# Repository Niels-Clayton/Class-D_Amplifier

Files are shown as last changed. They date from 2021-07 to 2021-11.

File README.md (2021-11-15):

# [D-Class Amplifier](https://niels-clayton.github.io/D-Class_Amplifier/)
ECEN405 Class-D amplifier group project

**Team members:**

- Daniel Eisen
- Nickolai Wolfe
- Niels Clayton

---
## Input Filter Stage

- The input stage will use two active filters, a 10Hz corner frequency high pass filter, and a 200Hz corner frequency low pass filter. This will provide an overall filter passband of 10Hz - 200Hz.

---
## S-PWM Generation

- It is important to be able to effectively filter out the switching frequency of the sinusoidal pulse width modulated (SPWM) signal output. because of this, we want to ensure that the switching frequency is at least two decades above the maximum output frequency. This will ensure an attenuation of at least 40dB of the switching noise by the output filter.

- Our output frequency range is 10Hz - 200Hz. To achieve the required attenuation of the switching frequency, it will nee to be 20kHz.

---
## Power Stage
- 2x IR21834PBF drivers
  - V_offset: 600V max
  - I_o+-: 1.4A/1.8A
  - T_on/off: 180ns/220ns
  - MT: 35ns
  - V_cc: 10-20V (single)
  - V_in: Vss+5V
- 4x PHP23NQ11T,127 Fets
  - minimum BV_dss of 45V
  - Actual: 110V
  - Gate Charge Qg: 10nC
  - Rdson: 49m 

https://www.infineon.com/dgdl/Infineon-Using_Monolithic_Voltage_Gate_Drivers-AN-v01_00-EN.pdf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
---
## Output filter
Signal freq max of 200Hz, Switching frequency of ~25kHz
Place corner frequency of filter at 2kHz (decade centred)
mes

https://datasheets.maximintegrated.com/en/ds/MAX4295.pdf

Figure 4c. Alternate Balanced 2-Pole Filter

Balanced 2-Pole (Figure 4b):
A  balanced  2-pole  filter  does  not  have  the  common-
mode swing problem of the single-ended filter.
C = 2 / (√2 ✕ RL ✕ ωo), L = (√2 ✕ RL)/(2 ✕ ωo); choosing
fo =  30kHz  and  RL =  4Ω,  C1a  =  C1b  =  2.0μF,  L1a  =
L1b = 15μH.
A single capacitor connected across RL, with a value of
CL = 1/(√2 ✕ RL ✕ ωo), can be used in place of C1a and
C1b.  However,  the  configuration  as  shown  gives  an
improved  rejection  to  common-mode  signal  compo-
nents  of  OUT+_  and  OUT-_.    If  the  single  capacitor
scheme is used, additional capacitors (Ca and Cb) can
be  added  from  each  side  of  RL,  providing  a  high-fre-
quency  short  to  ground  (Figure  4c).  These  capacitors
should be approximately 0.2 ✕ CL.

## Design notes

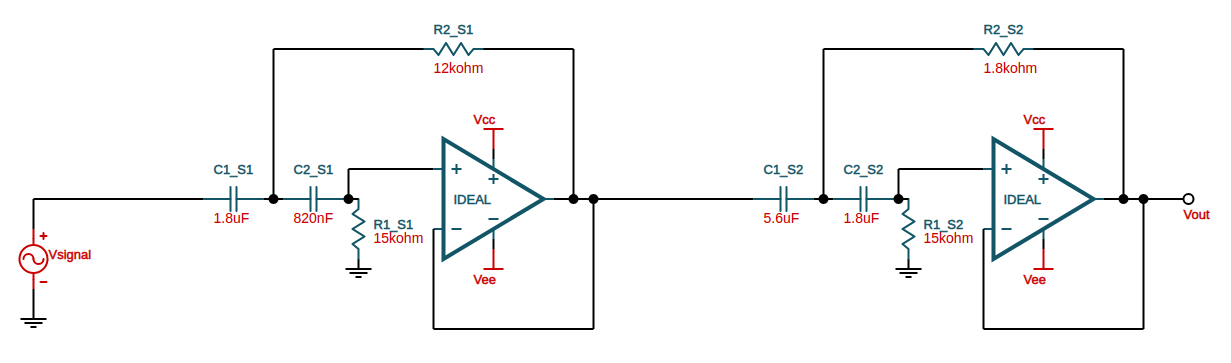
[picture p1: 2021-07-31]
docs/images/input_HPF_design.png

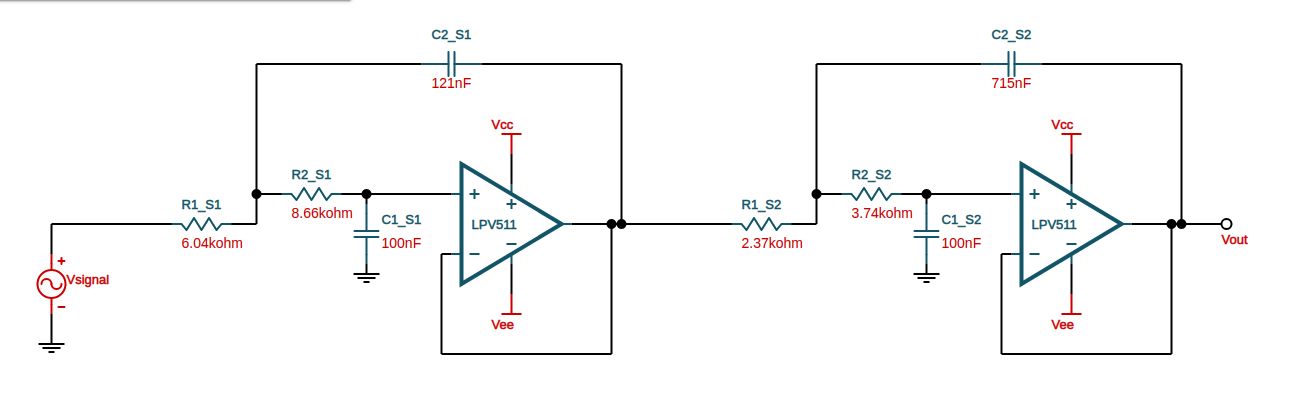
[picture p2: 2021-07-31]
docs/images/input_LPF_design.png

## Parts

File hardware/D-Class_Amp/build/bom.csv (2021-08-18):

Supplier | Part Number | Qty | Description
Digi-Key | CL21A106KOQNNWE | 12 | 10uF 16V
Digi-Key | UVR1H102MHD1TO | 3 | 1000uF 50V
Digi-Key | 885012207051 | 6 | 1uF 16V
Digi-Key | 865080142007 | 3 | 100uF 6.3V
Digi-Key | CL21B154KOANNNC | 3 | 150nF 16V
Digi-Key | 885012207045 | 15 | 100nF 16V
Digi-Key | L21A225KOFNNNE | 3 | 2.2uF 16V
Digi-Key | CL21B684KOFNNNG | 3 | 680nF 16V
Digi-Key | C0805C125K4PAC7800 | 3 | 1.2uF 16V
Digi-Key | 885012207040 | 3 | 15nF 16V
Digi-Key | 865080640001 | 6 | 1uF 50V
Digi-Key | C4AQJLU5100M19J | 3 | 10u 700V
Digi-Key | CL21B474KBFNNNG | 6 | 0.47uF 50V
Digi-Key | UG1B-E3/54 | 6 | Vishay Diode 100V 1A
Digi-Key | HCTI-150-5.0 | 6 | 150uF
Digi-Key | PHP23NQ11T,127 | 12 | PHP23NQ11T
Digi-Key | RC0805JR-0710KL | 27 | 10k
Digi-Key | RC0805JR-074K3L | 3 | 4.3k
Digi-Key | RC0805JR-075K6L | 3 | 5.6k
Digi-Key | CRCW08051K50FKEAC | 3 | 1.5k
Digi-Key | ERA-6AED242V | 3 | 2.4k
Digi-Key | RC0805JR-078K2L | 3 | 8.2k
Digi-Key | RC0805JR-0715KL | 3 | 15k
Digi-Key | RC0805JR-0710KL | 3 | 1k
Digi-Key | ERJ-6ENF10R0V | 12 | 10 ohms
Digi-Key | CT6EP203 | 3 | 20k
Digi-Key | CT6EP502 | 3 | 5k
Digi-Key | CT6EP102 | 3 | 1k
Digi-Key | NCP1117DT12G | 3 | IC REG LINEAR 12V 1A DPAK
Digi-Key | MCP1799T-5002H/TT | 3 | IC REG LINEAR 5V 80MA SOT23-3
Digi-Key | LM324DR | 3 | IC OPAMP GP 4 CIRCUIT 14SOIC
Digi-Key | TL972IDR | 3 | IC OPAMP GP 2 CIRCUIT 8SOIC
Digi-Key | LMV393S-13 | 3 | IC COMPARATOR TINY LV 8-SO
Digi-Key | IR21834SPBFDKR-ND | 6 | IC GATE DRVR HALF-BRIDGE 14SOIC

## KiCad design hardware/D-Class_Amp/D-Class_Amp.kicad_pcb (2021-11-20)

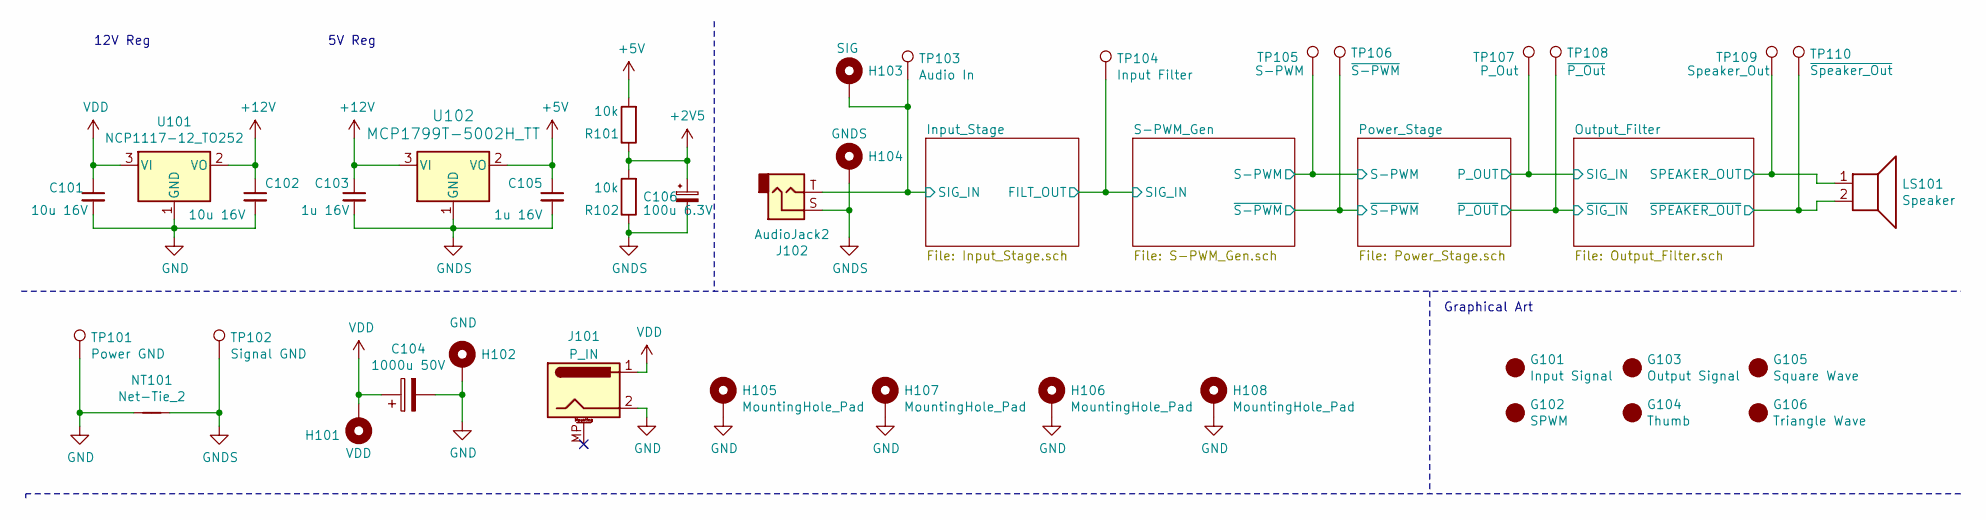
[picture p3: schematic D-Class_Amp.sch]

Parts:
C101, C102: 10u 16V; C_0805_2012Metric_Pad1.18x1.45mm_HandSolder; Part Number CL21A106KOQNNWE; DigiKey Price 0.34
C103, C105: 1u 16V; C_0805_2012Metric_Pad1.18x1.45mm_HandSolder; Part Number 885012207051; DigiKey Price 0.16
C104: 1000u 50V; CP_Radial_D10.0mm_P5.00mm; Part Number UVR1H102MHD1TO; DigiKey Price 1
C106: 100u 6.3V; CP_Elec_4x5.4; Part Number 885012207051; DigiKey Price 0.16
G101: Input Signal; sine
G102: SPWM
G103: Output Signal; sine
G104: Thumb; thumb
G105: Square Wave; square
G106: Triangle Wave; triangle
H101: VDD; MountingHole_3mm_Pad_Via
H102: GND; MountingHole_3mm_Pad_Via
H103: SIG; MountingHole_3mm_Pad_Via
H104: GNDS; MountingHole_3mm_Pad_Via
H105, H106, H107, H108: MountingHole_Pad; MountingHole_3.2mm_M3_ISO14580_Pad
J101: P_IN; BarrelJack_Horizontal; Part Number PJ-002BH; DigiKey Price 1.20
J102: AudioJack2; CUI_MJ-63022A; Part Number MJ-63022A; DigiKey Price 2.27
LS101: Speaker
NT101: Net-Tie_2; NetTie-2_SMD_Pad2.0mm
R101, R102: 10k; R_0805_2012Metric_Pad1.20x1.40mm_HandSolder; Part Number RC0805JR-0710KL; DigiKey Price 0.16
TP101: Power GND; TestPoint_THTPad_D1.0mm_Drill0.5mm
TP102: Signal GND; TestPoint_THTPad_D1.0mm_Drill0.5mm
TP103: Audio In; TestPoint_THTPad_D1.0mm_Drill0.5mm
TP104: Input Filter; TestPoint_THTPad_D1.0mm_Drill0.5mm
TP105: S-PWM; TestPoint_THTPad_D1.0mm_Drill0.5mm
TP106: ~S-PWM; TestPoint_THTPad_D1.0mm_Drill0.5mm
TP107: P_Out; TestPoint_THTPad_D1.0mm_Drill0.5mm
TP108: ~P_Out; TestPoint_THTPad_D1.0mm_Drill0.5mm
TP109: Speaker_Out; TestPoint_THTPad_D1.0mm_Drill0.5mm
TP110: ~Speaker_Out; TestPoint_THTPad_D1.0mm_Drill0.5mm
U101: NCP1117-12_TO252; TO-252-2; Part Number NCP1117DT12G; DigiKey Price 1.18
U102: MCP1799T-5002H_TT; SOT-23_Handsoldering; Part Number MCP1799T-5002H/TT; DigiKey Price 0.62

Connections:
+2V5: C106.1, R101.1, R102.2; also elsewhere on the board
+5V: C105.1, R101.2, U102.2 (VO); also elsewhere on the board
+12V: C102.1, C103.1, U101.2 (VO), U102.3 (VI); also elsewhere on the board
/Input_Stage/FILT_OUT: TP104.1; also elsewhere on the board
/Input_Stage/SIG_IN: H103.1, J102.T, TP103.1; also elsewhere on the board
/Output_Filter/SPEAKER_OUT: LS101.1, TP109.1; also elsewhere on the board
/Output_Filter/~SPEAKER_OUT: LS101.2, TP110.1; also elsewhere on the board
/Power_Stage/P_OUT: TP107.1; also elsewhere on the board
/Power_Stage/S-PWM: TP105.1; also elsewhere on the board
/Power_Stage/~P_OUT: TP108.1; also elsewhere on the board
/Power_Stage/~S-PWM: TP106.1; also elsewhere on the board
GND: C101.2, C102.2, C104.2, H102.1, H105.1, H106.1, H107.1, H108.1, J101.2, NT101.1, TP101.1, U101.1 (GND); also elsewhere on the board
GNDS: C103.2, C105.2, C106.2, H104.1, J102.S, NT101.2, R102.1, TP102.1, U102.1 (GND); also elsewhere on the board
VDD: C101.1, C104.1, H101.1, J101.1, U101.3 (VI); also elsewhere on the board

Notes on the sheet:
12V Reg
5V Reg
Graphical Art

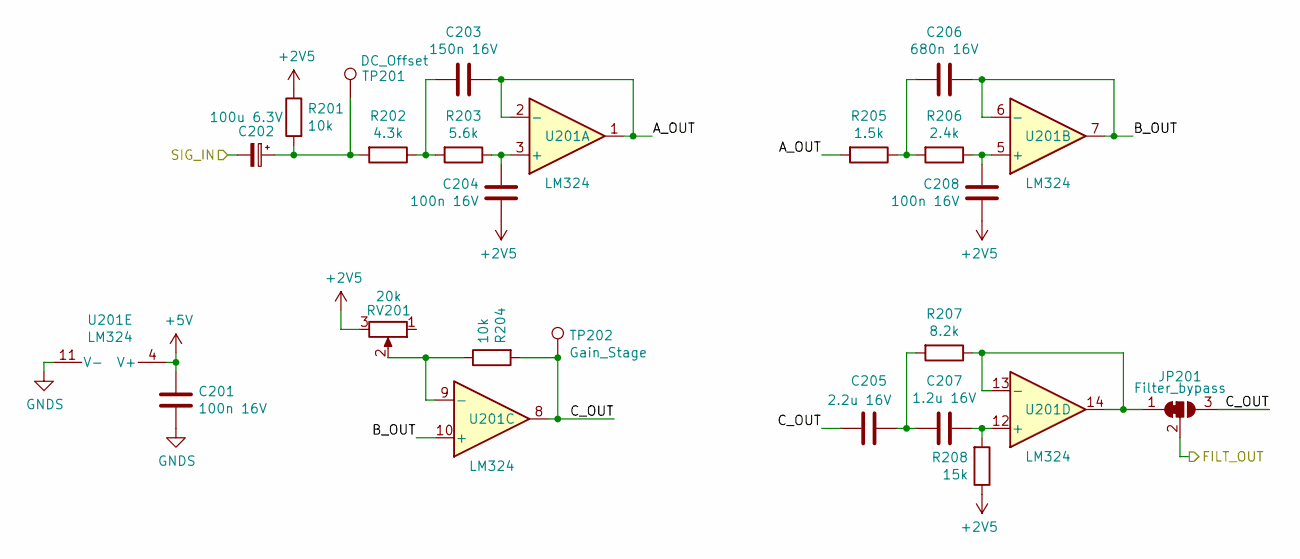
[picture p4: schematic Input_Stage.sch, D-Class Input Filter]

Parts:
C201, C204, C208: 100n 16V; C_0805_2012Metric_Pad1.18x1.45mm_HandSolder; Part Number 885012207045; DigiKey Price 0.16
C202: 100u 6.3V; CP_Elec_4x5.4; Part Number 865080142007; DigiKey Price 0.32
C203: 150n 16V; C_0805_2012Metric_Pad1.18x1.45mm_HandSolder; Part Number CL21B154KOANNNC; DigiKey Price 0.16
C205: 2.2u 16V; C_0805_2012Metric_Pad1.18x1.45mm_HandSolder; Part Number L21A225KOFNNNE; DigiKey Price 0.26
C206: 680n 16V; C_0805_2012Metric_Pad1.18x1.45mm_HandSolder; Part Number CL21B684KOFNNNG; DigiKey Price 0.16
C207: 1.2u 16V; C_0805_2012Metric_Pad1.18x1.45mm_HandSolder; Part Number C0805C125K4PAC7800; DigiKey Price 0.67
JP201: Filter_bypass; SolderJumper-3_P1.3mm_Bridged12_RoundedPad1.0x1.5mm_NumberL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
R201, R204: 10k; R_0805_2012Metric_Pad1.20x1.40mm_HandSolder; Part Number RC0805JR-0710KL; DigiKey Price 0.16
R202: 4.3k; R_0805_2012Metric_Pad1.20x1.40mm_HandSolder; Part Number RC0805JR-074K3L; DigiKey Price 0.16
R203: 5.6k; R_0805_2012Metric_Pad1.20x1.40mm_HandSolder; Part Number RC0805JR-075K6L; DigiKey Price 0.16
R205: 1.5k; R_0805_2012Metric_Pad1.20x1.40mm_HandSolder; Part Number CRCW08051K50FKEAC; DigiKey Price 0.16
R206: 2.4k; R_0805_2012Metric_Pad1.20x1.40mm_HandSolder; Part Number ERA-6AED242V; DigiKey Price 0.16
R207: 8.2k; R_0805_2012Metric_Pad1.20x1.40mm_HandSolder; Part Number RC0805JR-078K2L; DigiKey Price 0.16
R208: 15k; R_0805_2012Metric_Pad1.20x1.40mm_HandSolder; Part Number RC0805JR-0715KL; DigiKey Price 0.16
RV201: 20k; Potentiometer_Vishay_T73YP_Vertical; Part Number CT6EP203; DigiKey Price 1.25
TP201: DC_Offset; TestPoint_THTPad_D1.0mm_Drill0.5mm
TP202: Gain_Stage; TestPoint_THTPad_D1.0mm_Drill0.5mm
U201: LM324; SOIC-14_3.9x8.7mm_P1.27mm; Part Number LM324DR; DigiKey Price 0.62

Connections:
+2V5: C204.1, C208.1, R201.1, R208.1, RV201.3; also elsewhere on the board
+5V: C201.1, U201.4 (V+); also elsewhere on the board
/Input_Stage/A_OUT: C203.1, R205.2, U201.1, U201.2 (-)
/Input_Stage/B_OUT: C206.1, U201.6 (-), U201.7, U201.10 (+)
/Input_Stage/C_OUT: C205.2, JP201.3 (B), R204.2, TP202.1, U201.8
/Input_Stage/FILT_OUT: JP201.2 (C); also elsewhere on the board
/Input_Stage/SIG_IN: C202.2; also elsewhere on the board
GNDS: C201.2, U201.11 (V-); also elsewhere on the board
unnamed: C202.1, R201.2, R202.2, TP201.1
unnamed: C203.2, R202.1, R203.2
unnamed: C204.2, R203.1, U201.3 (+)
unnamed: C205.1, C207.2, R207.2
unnamed: C206.2, R205.1, R206.2
unnamed: C207.1, R208.2, U201.12 (+)
unnamed: C208.2, R206.1, U201.5 (+)
unnamed: JP201.1 (A), R207.1, U201.13 (-), U201.14
unnamed: R204.1, RV201.2, U201.9 (-)

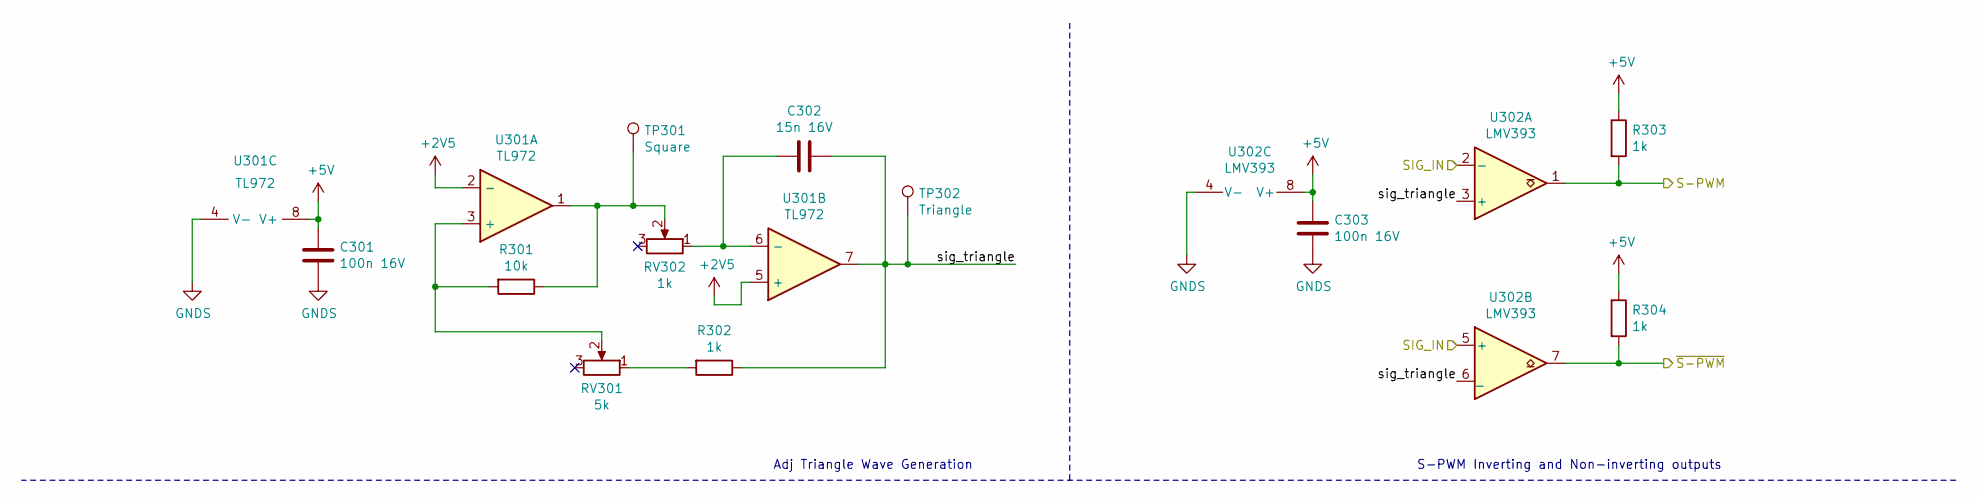
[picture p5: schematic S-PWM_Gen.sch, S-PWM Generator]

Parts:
C301, C303: 100n 16V; C_0805_2012Metric_Pad1.18x1.45mm_HandSolder; Part Number 885012207045; DigiKey Price 0.16
C302: 15n 16V; R_0805_2012Metric_Pad1.20x1.40mm_HandSolder; Part Number 885012207040; DigiKey Price 0.16
R301: 10k; R_0805_2012Metric_Pad1.20x1.40mm_HandSolder; Part Number RC0805JR-0710KL; DigiKey Price 0.16
R302, R303, R304: 1k; R_0805_2012Metric_Pad1.20x1.40mm_HandSolder; Part Number RC0805JR-0710KL; DigiKey Price 0.16
RV301: 5k; Potentiometer_Vishay_T73YP_Vertical; Part Number CT6EP502; DigiKey Price 1.25
RV302: 1k; Potentiometer_Vishay_T73YP_Vertical; Part Number CT6EP102; DigiKey Price 1.25
TP301: Square; TestPoint_THTPad_D1.0mm_Drill0.5mm
TP302: Triangle; TestPoint_THTPad_D1.0mm_Drill0.5mm
U301: TL972; SOIC-8_3.9x4.9mm_P1.27mm; Part Number TL972IDR; DigiKey Price 1.47
U302: LMV393; SOIC-8_3.9x4.9mm_P1.27mm; Part Number LMV393S-13; DigiKey Price 0.75

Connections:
+2V5: U301.2 (-), U301.5 (+); also elsewhere on the board
+5V: C301.1, C303.1, R303.1, R304.1, U301.8 (V+), U302.8 (V+); also elsewhere on the board
/Input_Stage/FILT_OUT: U302.2 (-), U302.5 (+); also elsewhere on the board
/Power_Stage/S-PWM: R303.2, U302.1; also elsewhere on the board
/Power_Stage/~S-PWM: R304.2, U302.7; also elsewhere on the board
/S-PWM_Gen/sig_triangle: C302.1, R302.1, TP302.1, U301.7, U302.3 (+), U302.6 (_)
GNDS: C301.2, C303.2, U301.4 (V-), U302.4 (V-); also elsewhere on the board
unnamed: C302.2, RV302.1, U301.6 (-)
unnamed: R301.1, RV302.2, TP301.1, U301.1
unnamed: R301.2, RV301.2, U301.3 (+)
unnamed: R302.2, RV301.1

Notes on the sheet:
Adj Triangle Wave Generation
S-PWM Inverting and Non-inverting outputs

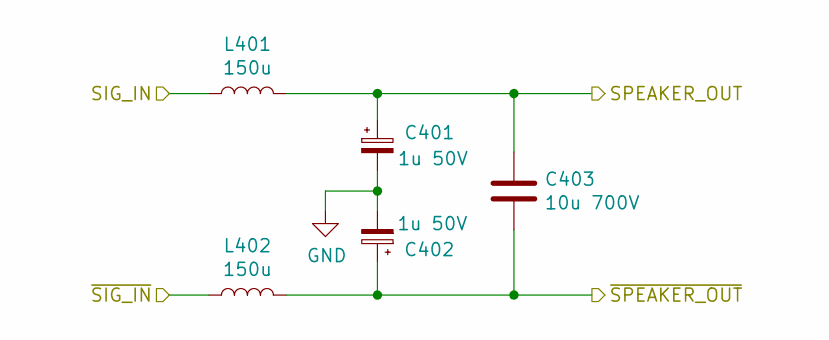
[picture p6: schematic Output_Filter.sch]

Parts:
C401, C402: 1u 50V; CP_Elec_4x5.4; Part Number 865080640001; DigiKey Price 0.29
C403: 10u 700V; C4AQJLU5100M19J_film_capacitor; Part Number C4AQJLU5100M19J; DigiKey Price 5.67
L401, L402: 150u; IND_HCTI-150-5.0; Part Number HCTI-150-5.0; DigiKey Price 4.20

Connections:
/Output_Filter/SPEAKER_OUT: C401.1, C403.1, L401.2; also elsewhere on the board
/Output_Filter/~SPEAKER_OUT: C402.1, C403.2, L402.2; also elsewhere on the board
/Power_Stage/P_OUT: L401.1; also elsewhere on the board
/Power_Stage/~P_OUT: L402.1; also elsewhere on the board
GND: C401.2, C402.2; also elsewhere on the board

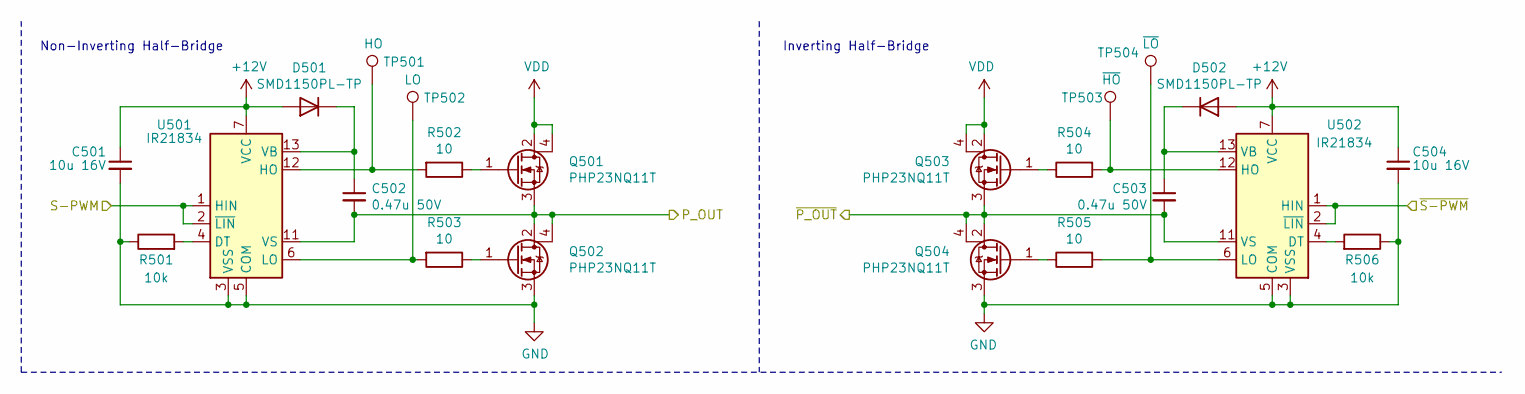
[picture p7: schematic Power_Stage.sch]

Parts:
C501, C504: 10u 16V; C_0805_2012Metric_Pad1.18x1.45mm_HandSolder; Part Number CL21A106KOQNNWE; DigiKey Price 0.34
C502, C503: 0.47u 50V; C_0805_2012Metric_Pad1.18x1.45mm_HandSolder; Part Number CL21B474KBFNNNG; DigiKey Price 0.16
D501, D502: SMD1150PL-TP; D_SOD-123F; Part Number UG1B-E3/54; DigiKey Price 0.67
Q501, Q502, Q503, Q504: PHP23NQ11T; Part Number PHP23NQ11T,127; DigiKey Price 1.90
R501, R506: 10k; R_0805_2012Metric_Pad1.20x1.40mm_HandSolder; Part Number RC0805JR-0710KL; DigiKey Price 0.16
R502, R503, R504, R505: 10; R_0805_2012Metric_Pad1.20x1.40mm_HandSolder; Part Number ERJ-6ENF10R0V; DigiKey Price 0.16
TP501: HO; TestPoint_THTPad_D1.0mm_Drill0.5mm
TP502: LO; TestPoint_THTPad_D1.0mm_Drill0.5mm
TP503: ~HO; TestPoint_THTPad_D1.0mm_Drill0.5mm
TP504: ~LO; TestPoint_THTPad_D1.0mm_Drill0.5mm
U501, U502: IR21834; SOIC-14_3.9x8.7mm_P1.27mm; Part Number IR21834SPBFDKR-ND; DigiKey Price 5.87

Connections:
+12V: C501.1, C504.1, D501.2 (A), D502.2 (A), U501.7 (VCC), U502.7 (VCC); also elsewhere on the board
/Power_Stage/P_OUT: C502.2, Q501.3 (S), Q502.2 (D), Q502.4 (D), U501.11 (VS); also elsewhere on the board
/Power_Stage/S-PWM: U501.1 (HIN), U501.2 (~LIN); also elsewhere on the board
/Power_Stage/~P_OUT: C503.2, Q503.3 (S), Q504.2 (D), Q504.4 (D), U502.11 (VS); also elsewhere on the board
/Power_Stage/~S-PWM: U502.1 (HIN), U502.2 (~LIN); also elsewhere on the board
GND: C501.2, C504.2, Q502.3 (S), Q504.3 (S), R501.1, R506.1, U501.3 (VSS), U501.5 (COM), U502.3 (VSS), U502.5 (COM); also elsewhere on the board
unnamed: C502.1, D501.1 (K), U501.13 (VB)
unnamed: C503.1, D502.1 (K), U502.13 (VB)
unnamed: Q501.1 (G), R502.1
unnamed: Q502.1 (G), R503.1
unnamed: Q503.1 (G), R504.1
unnamed: Q504.1 (G), R505.1
unnamed: R501.2, U501.4 (DT)
unnamed: R502.2, TP501.1, U501.12 (HO)
unnamed: R503.2, TP502.1, U501.6 (LO)
unnamed: R504.2, TP503.1, U502.12 (HO)
unnamed: R505.2, TP504.1, U502.6 (LO)
unnamed: R506.2, U502.4 (DT)
VDD: Q501.2 (D), Q501.4 (D), Q503.2 (D), Q503.4 (D); also elsewhere on the board

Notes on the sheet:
Non-Inverting Half-Bridge
Inverting Half-Bridge

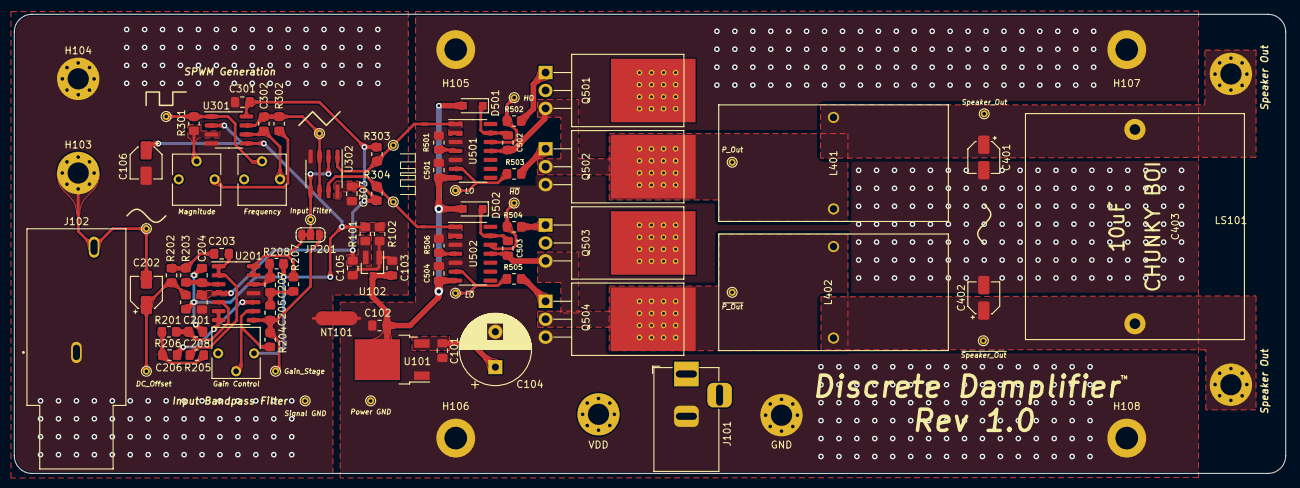
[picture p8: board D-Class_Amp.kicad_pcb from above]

Board: 2 copper layers, 180.0 x 65.0 mm, 99 parts (1 on the bottom side), 43 nets.

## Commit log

2021-07-30 added kicad project
    [D-Class_Amp.kicad_pcb, D-Class_Amp.sch]
2021-07-30 Added Input_Stage sheet and SPICE simulation file.
    [Input_Stage.sch]
2021-07-31 all stages genned
    [D-Class_Amp.sch, Output_Filter.sch, Power_Stage.sch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]
2021-07-31 Added documentation directory; built LPF input filter simulation.
2021-07-31 power stage
2021-07-31 driver selection
2021-07-31 Driver key ref
2021-07-31 Created the input filter schematic
    [Input_Stage.sch]
2021-07-31 fet specced
2021-07-31 added parts
    [Power_Stage.sch]
2021-07-31 edited input filter ground, created schematic for the SPWM generator
    [D-Class_Amp.sch, Input_Stage.sch, S-PWM_Gen.sch]
2021-07-31 Updated input filter spice model.
2021-07-31 grounded man how it work
    [Power_Stage.sch]
2021-07-31 Added an input barel jack
    [D-Class_Amp.sch, S-PWM_Gen.sch]
2021-07-31 Selected Op-Amp for input stage and labelled parts
    [Input_Stage.sch]
2021-07-31 Set footprints for the input stage components.
    [Input_Stage.sch]
2021-07-31 update the letspice model so that the trianlge wave goes from rail to rail. Also added a potentiometer to the feedback path of the triangle wave generator, allowing for precise tuning of this gain.
    [S-PWM_Gen.sch]
2021-08-01 Added gain stage to input filter spice simulation
2021-08-01 un-bold the font :)
    [S-PWM_Gen.sch]
2021-08-01 Changed gain stage's resistors to be E12 series
2021-08-01 layout 1st pass
    [Power_Stage.sch]
2021-08-02 single side
    [D-Class_Amp.sch, Input_Stage.sch, Output_Filter.sch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]
2021-08-02 update potentiometer, add footprints
    [S-PWM_Gen.sch]
2021-08-02 deat time and values, 12v reg
    [Power_Stage.sch]
2021-08-03 Added input bias circuit and gain stage to input-stage schematic.
    [D-Class_Amp.sch, Input_Stage.sch, Output_Filter.sch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]
2021-08-04 added resistor values
    [Input_Stage.sch]
2021-08-04 update the SPW generator to work with a single 5V rail
2021-08-04 footed ic
    [Power_Stage.sch]
2021-08-04 added footprints for opamp
    [S-PWM_Gen.sch]
2021-08-04 select comparator and set footprint
    [S-PWM_Gen.sch]
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2021-08-06 updated input stage schematic
    [Input_Stage.sch]
2021-08-09 fixed remerge
    [Output_Filter.sch, Power_Stage.sch]
2021-08-10 output filter comp. TODO real vals
2021-08-10 rebuilt input to match
    [D-Class_Amp.sch, Output_Filter.sch]
2021-08-10 updated SPWM model with new comparators, also added test points to schematic and fixed MOSFET footprints
    [D-Class_Amp.sch, Power_Stage.sch, S-PWM_Gen.sch]
2021-08-10 Added potentiometer to input gain stage, assigned all input footprints
    [D-Class_Amp.kicad_pcb, D-Class_Amp.sch, Input_Stage.sch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]
2021-08-10 Started input stage layout
    [D-Class_Amp.kicad_pcb, Input_Stage.sch]
2021-08-10 added the 5V regulator and updated footprints
    [D-Class_Amp.sch, Power_Stage.sch, S-PWM_Gen.sch]
2021-08-11 added footprint to 5V reg
    [D-Class_Amp.sch]
2021-08-11 Positioned passives around LM324
    [D-Class_Amp.kicad_pcb]
2021-08-11 Positioned all passives for the input stage; started trace layout
    [D-Class_Amp.kicad_pcb]
2021-08-11 updated the Spice sim and added the footprints to the comparator
    [S-PWM_Gen.sch]
2021-08-11 supply cap and design notes
    [Power_Stage.sch]
2021-08-11 updated fet footprints, and added power stage test points
    [D-Class_Amp.sch, Power_Stage.sch]
2021-08-11 re-added supply caps for the gate driver
    [Power_Stage.sch]
2021-08-11 Add footprints to the output filter and select output filter components
    [D-Class_Amp.sch, Output_Filter.sch, Power_Stage.sch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]
2021-08-11 lololol input filter hahaha teehee lolool
2021-08-11 Fixed the input filter spice simulation
2021-08-11 Updated and fixed the input filter schematic
    [Input_Stage.sch, Output_Filter.sch]
2021-08-11 updated the SPWM spice sim to be able to take the new gain stage audio input
2021-08-11 layed out the phase phucker
    [D-Class_Amp.kicad_pcb]
2021-08-11 added pricing and and part numbers to all components
    [D-Class_Amp.sch, Input_Stage.sch, Output_Filter.sch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]
2021-08-11 Updated input filter layout
    [D-Class_Amp.kicad_pcb]
2021-08-12 updated the BOM
    [D-Class_Amp.kicad_pcb, D-Class_Amp.sch, Power_Stage.sch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]
2021-08-12 Designed the triangle generator PCB layout, and the power switching stage layout
    [D-Class_Amp.kicad_pcb, D-Class_Amp.sch, Input_Stage.sch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]
2021-08-12 REGION CITY
    [D-Class_Amp.kicad_pcb]
2021-08-12 placed and routed all components, fixed the MOSFET footprints, and added all 3D models.
    [D-Class_Amp.kicad_pcb, D-Class_Amp.sch, Input_Stage.sch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]
2021-08-13 PCB done POG
    [D-Class_Amp-B_Cu.gbr, D-Class_Amp-B_Mask.gbr, D-Class_Amp-B_Paste.gbr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]
2021-08-17 created a bill of materials
    [D-Class_Amp.sch, Power_Stage.sch]
2021-09-13 goddam GNDS bck_plane
    [D-Class_Amp.kicad_pcb]
2021-10-13 update design
    [D-Class_Amp.sch, Power_Stage.sch, S-PWM_Gen.sch]
2021-10-15 res cap to ref
    [D-Class_Amp.kicad_pcb, D-Class_Amp.sch]
2021-10-18 teardrop ref cap, regen BOM
    [D-Class_Amp.kicad_pcb, D-Class_Amp.sch]
2021-10-18 readded art and regen bom
    [D-Class_Amp.kicad_pcb, D-Class_Amp.sch, Input_Stage.sch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]
2021-10-18 Revert "teardrop ref cap, regen BOM"
    This reverts commit 41e1c187b9f88871f416da328e72449a335824d4.
    [D-Class_Amp.kicad_pcb, D-Class_Amp.sch]
2021-10-18 hopefully fixed the repo
    [D-Class_Amp.kicad_pcb, D-Class_Amp.sch, Input_Stage.sch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]
2021-10-19 cleaned bars
    [Input_Stage.sch, Power_Stage.sch]
2021-10-20 rm ground planes from output zone
    [D-Class_Amp.kicad_pcb]
2021-10-21 fixed the inout filter gain stage
    [D-Class_Amp.kicad_pcb, Input_Stage.sch]
2021-11-04 update pcb and simulations of sampling
    [D-Class_Amp.kicad_pcb, S-PWM_Gen.sch]
2021-11-15 added graphical symbols, exchanged THT bootstrapping diodes for SMD diodes, updated BOM
    [D-Class_Amp.kicad_pcb, D-Class_Amp.sch, Power_Stage.sch]
2021-11-20 fixed traces extending beyond pads
    [D-Class_Amp.kicad_pcb]
